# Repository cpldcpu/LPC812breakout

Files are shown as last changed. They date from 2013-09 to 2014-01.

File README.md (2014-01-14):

LPC812breakout
==============

Breakout Board for the NXP LPC812M101JPH20 microcontroller. Includes push buttons for reset and activating the serial bootloader. 
The board has an integrated 500mA 3.3V LDO to supply both the MCU and connected devices from the USB port. 

The four pins on the top side (5V,RX,TX,GND) can be used to connect a cheap USB to serial adapter (<$2 on ebay) and program the device via the internal bootloader using FlashMagic. Note that you have to cross RX and TX. RX from the serial port goes to TX and vice versa for TX.

 * FlashMagic can be downloaded [here](http://www.flashmagictool.com/).
 * Developer environemt and LPC800 datasheets by NXP can be found  [here](http://www.lpcware.com/content/device/lpc800).

The entire board with LPC812 is smaller than a DIP LPC1114. See below for size comparison.

Bonus: Eagle Library for all LPC800 parts

You can order PCB's here: [Shared design at OSH Park](http://oshpark.com/shared_projects/rQra0bCX) The price is $3.30 including shipping for three boards.

Status
======

 - 2013/09/17 Untested. Board ordered at OSH park
 - 2013/09/29 Designed revision 2
 - 2013/10/?? Version 2 board received, built and tested. Everything works as intended.
 
## Top side ##
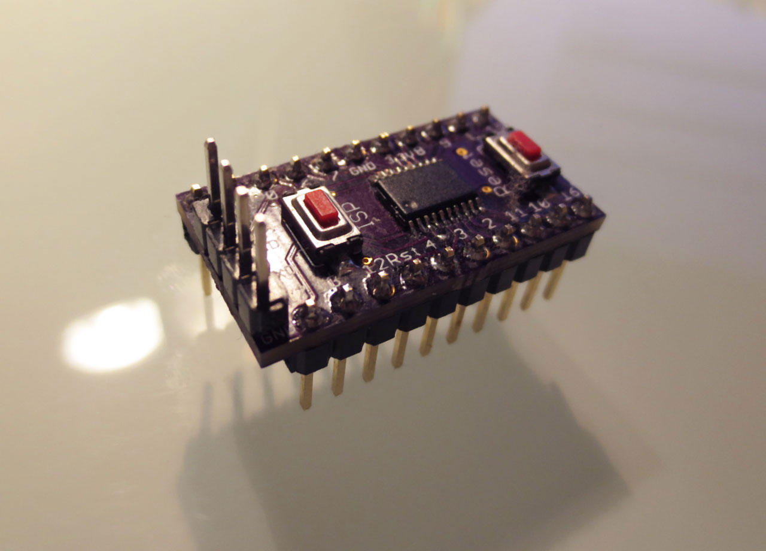
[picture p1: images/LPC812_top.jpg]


## Bottom ##
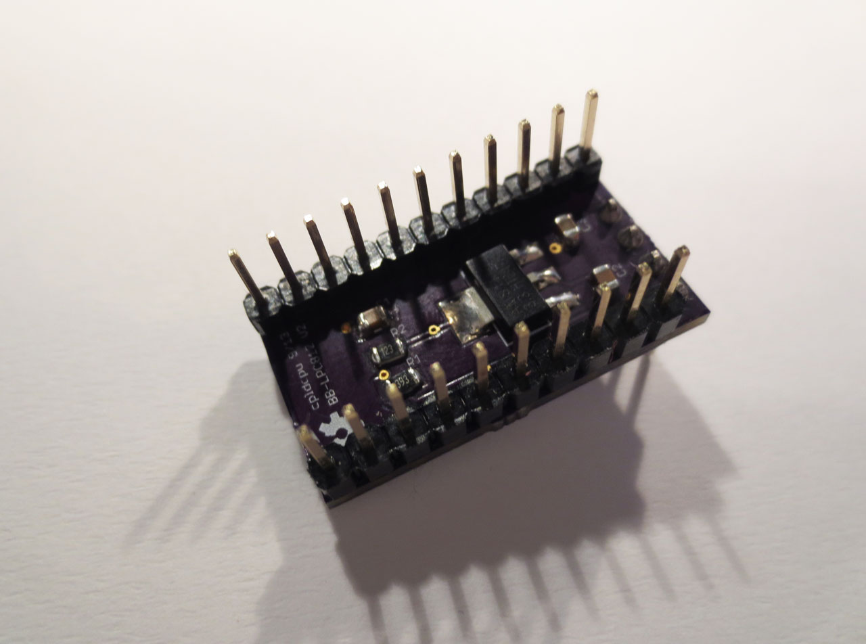
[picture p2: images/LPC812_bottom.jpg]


## Size comparison of first version to LPC1114 ##
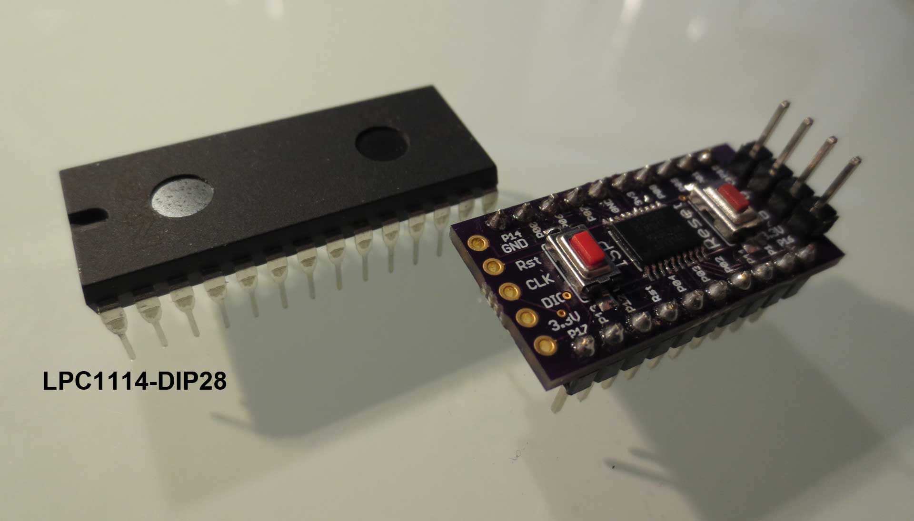
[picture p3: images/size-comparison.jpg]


## On breadboard ##
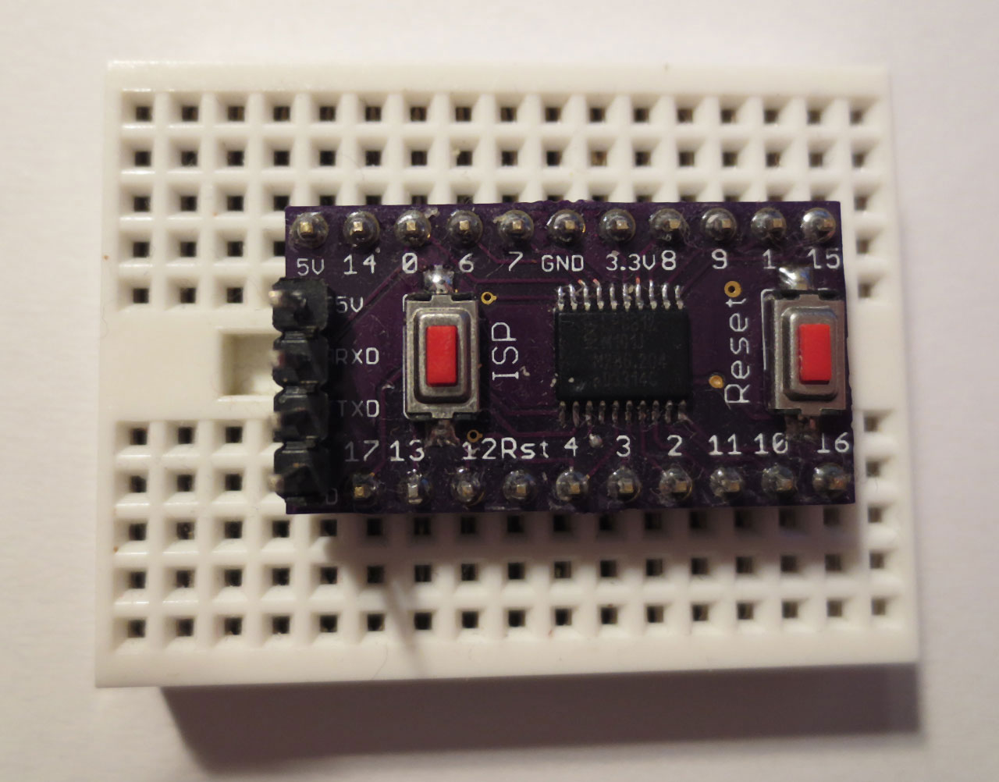
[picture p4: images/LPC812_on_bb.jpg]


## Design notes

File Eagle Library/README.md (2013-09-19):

Eagle-Library for NXP LPC800 series MCUs
========================================

All devices are untested. Use at your own risk.

| Device | Package |
| --- | --- |
| LPC810M021JN8 | DIP 8 |
| LPC811M001JDH16 | TSSOP 16 |
| LPC812M101JD20 | SOIC 20 |
| LPC812M101JDH16 | TSSOP 16 |
| LPC812M101JDH20 | TSSOP 20 |

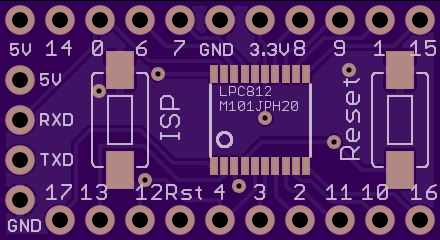
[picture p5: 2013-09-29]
images/top.png

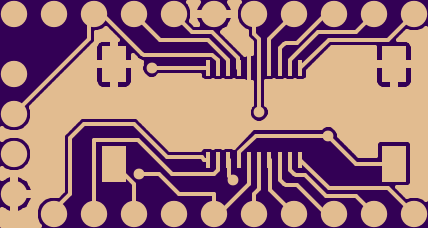
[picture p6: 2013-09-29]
images/top_copper.png

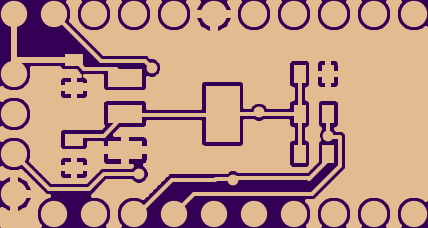
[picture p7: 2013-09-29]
images/bottom_copper.png

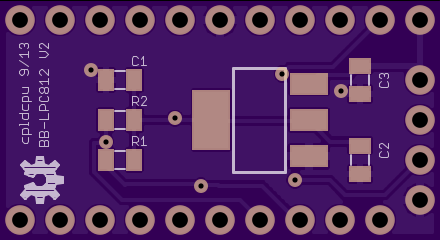
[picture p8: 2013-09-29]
images/bottom.png

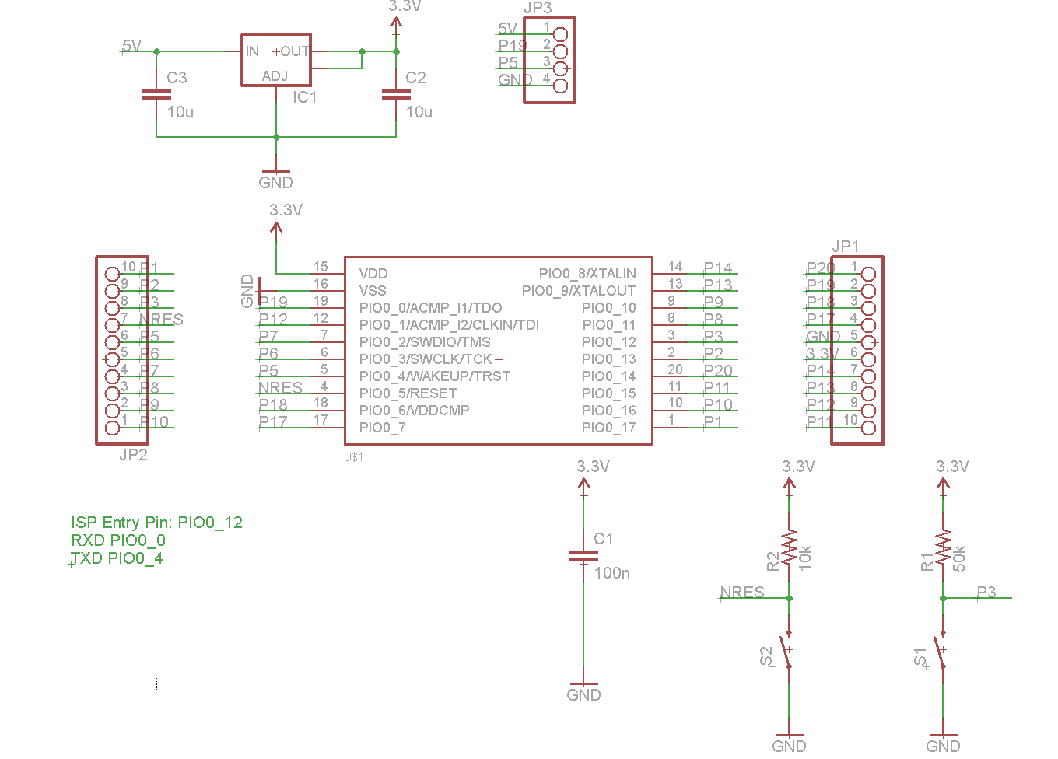
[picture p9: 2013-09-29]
images/circuit.png

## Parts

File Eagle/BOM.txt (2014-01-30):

# Part  Type            Value                         Package               Pins
1 C1    Capacitor       100n                          805                   2
2 C2    Cap. MLCC 10V   10u                           805                   2
3 C3    Cap. MLCC 10V   10u                           805                   2
4 IC1   LDO             AMS1117-3.3                   SOT223                3
5 R1    Resistor        50k                           805                   2
6 R2    Resistor        10k                           805                   2
7 S1    Pushbutton      SWITCH-MOMENTARY-2-SMD-1101NE TACTILE-SWITCH-1101NE 2
8 S2    Pushbutton      SWITCH-MOMENTARY-2-SMD-1101NE TACTILE-SWITCH-1101NE 2
9 IC2   Controller      NXP LPC812M101JDH20           TSSOP20               20

In addition:

10 	Pin Header	10x1
11 	Pin Header	11x1
12 	Pin Header	4x1

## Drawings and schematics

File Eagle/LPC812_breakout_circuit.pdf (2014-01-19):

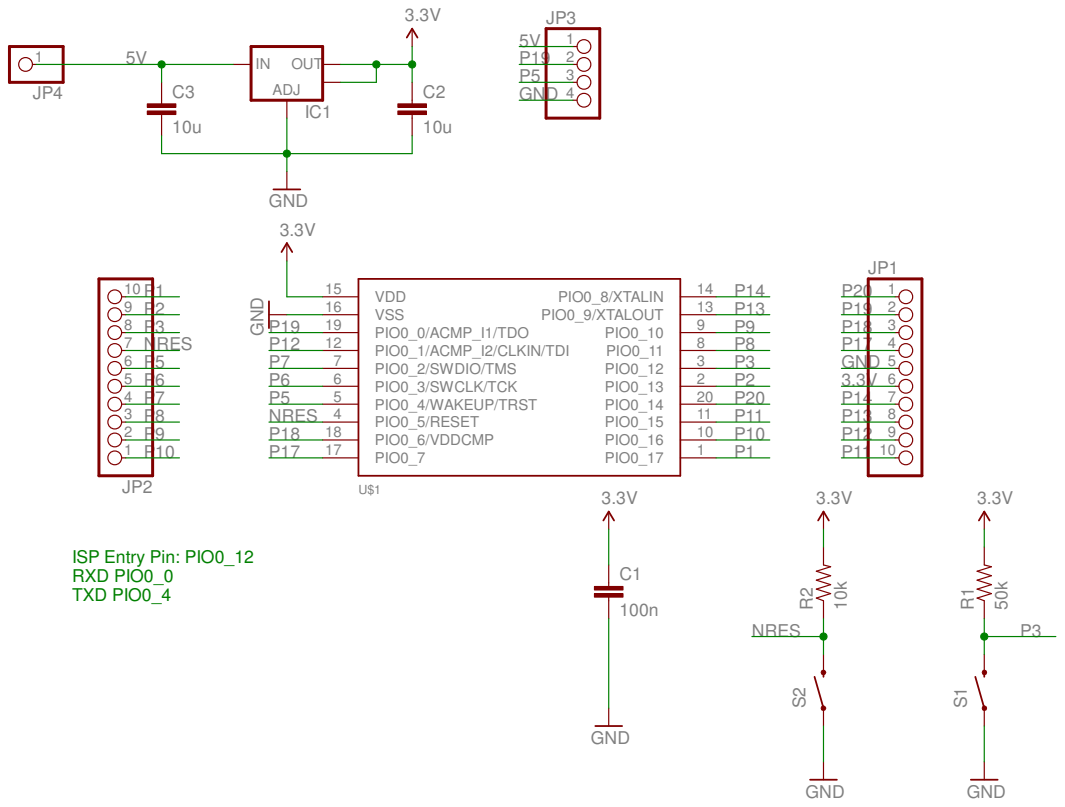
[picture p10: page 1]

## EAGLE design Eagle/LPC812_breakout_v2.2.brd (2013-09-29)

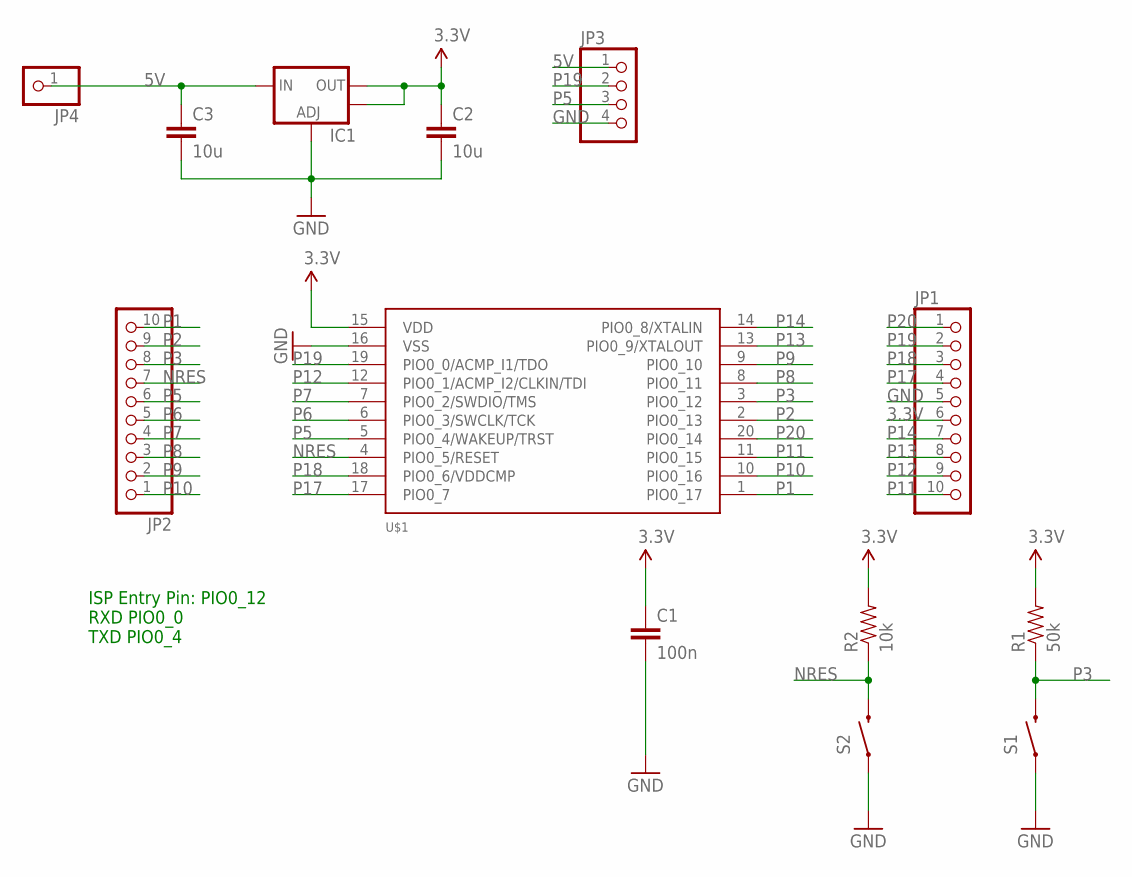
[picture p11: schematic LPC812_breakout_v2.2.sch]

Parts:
C1: 100n; 0805
C2, C3: 10u; 0805
IC1: V_REG_LM1117SOT223; SOT223
JP1, JP2: HEADER-1X10ROUND; 1X10_ROUND
JP3: HEADER-1X4ROUND; 1X04_ROUND
JP4: HEADER-1X1ROUND; 1X01_ROUND
R1: 50k; 0805
R2: 10k; 0805
S1, S2: SWITCH-MOMENTARY-2-SMD-1101NE; TACTILE-SWITCH-1101NE
U$1: LPC812M101JDH20; TSSOP20

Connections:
3.3V: C1.1, C2.1, IC1.2 (OUT), IC1.4 (OUT), JP1.6, R1.2, R2.2, U$1.15 (VDD)
5V: C3.1, IC1.3 (IN), JP3.1, JP4.1
GND: C1.2, C2.2, C3.2, IC1.1 (ADJ), JP1.5, JP3.4, S1.P$1 (1), S2.P$1 (1), U$1.16 (VSS)
NRES: JP2.7, R2.1, S2.P$2 (2), U$1.4 (PIO0_5/RESET)
P1: JP2.10, U$1.1 (PIO0_17)
P2: JP2.9, U$1.2 (PIO0_13)
P3: JP2.8, R1.1, S1.P$2 (2), U$1.3 (PIO0_12)
P5: JP2.6, JP3.3, U$1.5 (PIO0_4/WAKEUP/TRST)
P6: JP2.5, U$1.6 (PIO0_3/SWCLK/TCK)
P7: JP2.4, U$1.7 (PIO0_2/SWDIO/TMS)
P8: JP2.3, U$1.8 (PIO0_11)
P9: JP2.2, U$1.9 (PIO0_10)
P10: JP2.1, U$1.10 (PIO0_16)
P11: JP1.10, U$1.11 (PIO0_15)
P12: JP1.9, U$1.12 (PIO0_1/ACMP_I2/CLKIN/TDI)
P13: JP1.8, U$1.13 (PIO0_9/XTALOUT)
P14: JP1.7, U$1.14 (PIO0_8/XTALIN)
P17: JP1.4, U$1.17 (PIO0_7)
P18: JP1.3, U$1.18 (PIO0_6/VDDCMP)
P19: JP1.2, JP3.2, U$1.19 (PIO0_0/ACMP_I1/TDO)
P20: JP1.1, U$1.20 (PIO0_14)

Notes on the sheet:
ISP Entry Pin: PIO0_12 RXD PIO0_0 TXD PIO0_4

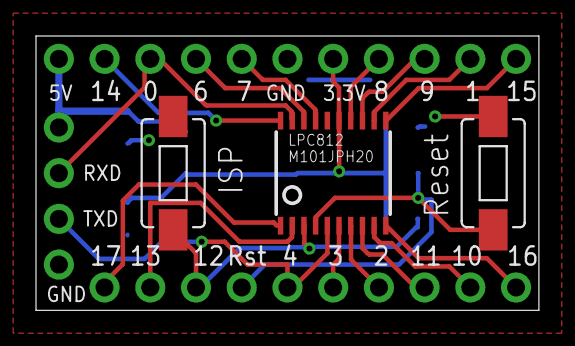
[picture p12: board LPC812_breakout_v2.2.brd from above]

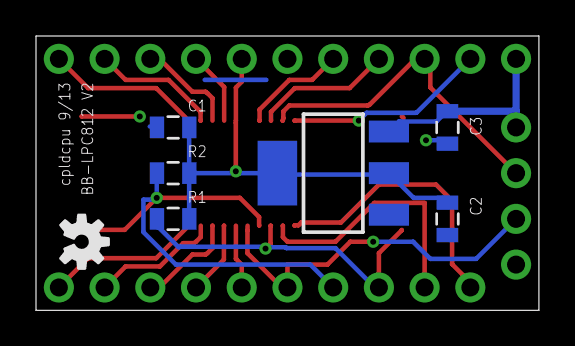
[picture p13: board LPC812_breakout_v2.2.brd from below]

Board: 2 copper layers, 27.9 x 15.2 mm, 14 parts (7 on the bottom side), 21 nets.

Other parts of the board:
U$2: OSHW-LOGO-S

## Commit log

2013-09-29 Revision 2
    Changes:
    - 10 mil traces, no 90° bends, ground plane where possible.
    - Font size for pin labelling increased.
    - Removed SWD port to reduce complexity and size. If needed, the board
    can be accessed at the broken out pins.
    - Included 3.3V regulator, since the driving ability of those includede
    in the USB to serial converters is limited.
    - Removed debouncing cap from reset switch.
    [LPC812_breakout_v2.0.brd, LPC812_breakout_v2.0.sch]
2013-09-29 Revision 2.2 - Broke out 5V pin
    [LPC812_breakout_v2.0.sch, LPC812_breakout_v2.2.brd]
2013-11-20 added schematics
    [LPC812_breakout_v2.2.sch]
2014-01-19 added schematics as pdf
2014-01-30 Added BOM

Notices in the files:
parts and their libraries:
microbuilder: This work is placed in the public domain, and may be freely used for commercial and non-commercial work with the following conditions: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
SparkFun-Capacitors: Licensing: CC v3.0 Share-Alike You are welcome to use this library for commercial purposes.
